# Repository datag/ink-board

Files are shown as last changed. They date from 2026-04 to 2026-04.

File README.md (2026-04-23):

# ink-board

A WiFi-connected tri-color ePaper display that shows a live dashboard — electricity price, solar power, weather, Bitcoin, and more — in a 3D-printed enclosure sitting on your desk.

<p align="center">
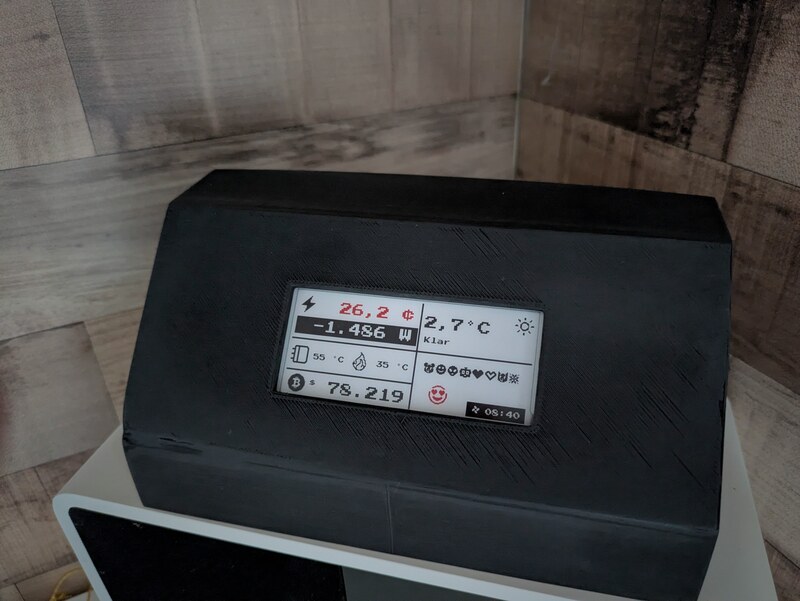
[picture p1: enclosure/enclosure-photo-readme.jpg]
ink-board on a desk, showing the live dashboard on its angled ePaper display
  
</p>

> [!NOTE]
> Most parts of this project — firmware, dashboard renderer, and enclosure design — were created with the help of AI. The whole thing is an experiment in building real hardware with AI assistance.

---

## How it works

```mermaid
graph TD
    A[Dashboard renderer<br/>Node.js] -->|POST /update — BMP over WiFi| B[ESP8266 firmware]
    B --> C[Waveshare 2.9&quot; B<br/>296 × 128 px · black / white / red]
    C --> D[3D-printed enclosure<br/>160 × 80 × 80 mm · 45° angled face]
    A -->|Fetches| E[(Live data<br/>Tibber · OpenMeteo · Binance · …)]
```

1. The **firmware** connects to WiFi and serves a small HTTP API. On boot it shows its IP address on the display.
2. The **dashboard renderer** runs on any machine on the same network, fetches live data from external APIs (Tibber, OpenMeteo, Binance, …), renders a 296 × 128 image, and pushes it to the device every few minutes.
3. The **enclosure** is a 3D-printed shell with a chamfered top edge so the display faces the viewer at a comfortable angle.

---

## Modules

| Module | Description | Docs |
|---|---|---|
| **Firmware** | ESP8266 Arduino sketch — WiFi, HTTP server, ePaper driver | [firmware.instructions.md](.github/instructions/firmware.instructions.md) |
| **Dashboard** | Node.js renderer — data fetching, SVG layout, BMP upload | [README.md](dashboard/README.md) · [dashboard.instructions.md](.github/instructions/dashboard.instructions.md) |
| **Enclosure** | OpenSCAD 3D-printable box with angled display window | [enclosure.instructions.md](.github/instructions/enclosure.instructions.md) |

---

## Hardware

| Part | Details |
|---|---|
| MCU | ESP8266 (NodeMCU 1.0 / ESP-12E) |
| Display | Waveshare 2.9" B V4 — 296 × 128 px, tri-color (black / white / red) |
| Interface | SPI (hardware) |
| Power | USB via NodeMCU onboard regulator |
| Enclosure | PLA, printed upside-down, no supports needed |

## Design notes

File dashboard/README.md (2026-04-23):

# ink-board Dashboard

## Setup

```shell
nvm use
npm install
```

> [!NOTE]
> Might require these dependencies to be installed globally:
> `sudo apt install libpixman-1-dev libcairo2-dev libpango1.0-dev libjpeg62-turbo-dev libgif-dev`

## Configure

Copy `dashboard.json5.example` to `dashboard.json5` and edit the configuration.

## Run

```shell
node render.js --config dashboard.json5

# Write SVG/PNG/BMP intermediate files but doesn't publish to device
node render.js --config dashboard.json5 --svg --png --bmp --dry-run
```

## Fetch data

```shell
# Run all enabled data-fetching scripts
node fetch.js --config dashboard.json5
```

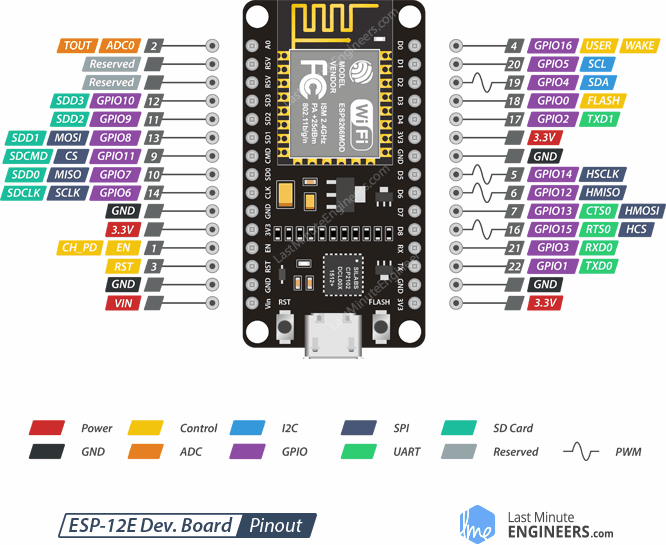
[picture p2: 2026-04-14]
firmware/doc/board-schematic.png

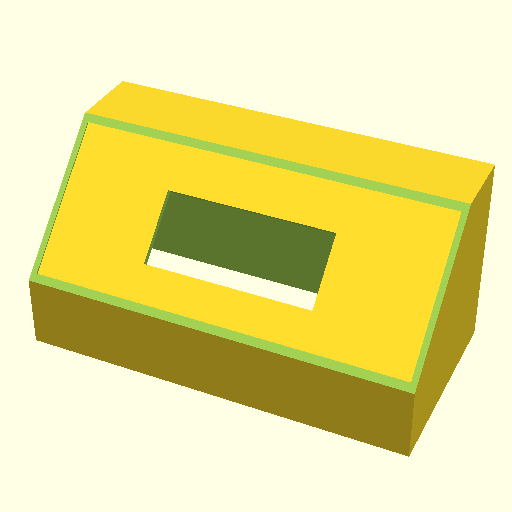
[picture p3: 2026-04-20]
enclosure/render_iso.png

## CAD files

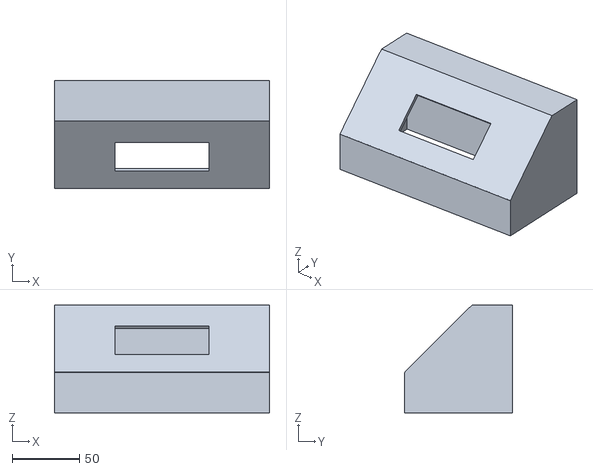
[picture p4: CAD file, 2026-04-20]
enclosure/ink-board.stl
160.0 x 80.0 x 80.0

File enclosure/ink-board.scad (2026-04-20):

// enclosure/ink-board.scad
// First-version: hollow box with 45° chamfer on long side
// No fillets, no display slot. Inner cavity clipped so angled face remains solid.

// Parameters
L = 160;      // outer length (mm)
W = 80;       // outer width  (mm)
H = 80;       // outer height (mm)
wall_t = 2.5; // wall thickness (mm)
chamfer = 50; // chamfer height from top (mm)

eps = 1; // small oversize to avoid boolean artifacts

module outer_box() {
  // bottom at Z=0 (open), extend to Z=H
  translate([0, 0, 0]) cube([L, W, H], center=false);
}

module inner_cavity() {
  // inner cavity extends up to leave wall_t at the top (fully hollow enclosure)
  inner_h = max(0, H - wall_t); // cavity height, leave top wall thickness
  inner_x = max(0, L - 2*wall_t);
  inner_y = max(0, W - 2*wall_t);
  translate([wall_t, wall_t, 0]) cube([inner_x, inner_y, inner_h], center=false);
}

module chamfer_wedge() {
  // Triangular prism removed from top-front-long edge
  // Built with linear_extrude of a right triangle as in model.txt
  points = [ [-H - eps, chamfer + eps], [-H - eps, 0], [-H + chamfer, 0] ];
  // rotate so extrusion axis aligns with world X
  rotate([0, 90, 0]) linear_extrude(height = L + 2*eps) polygon(points);
}

// Chamfer panel: solid panel that covers the chamfer face (thickness = wall_t)
module chamfer_panel() {
  // panel centered on chamfer face; small eps oversize to ensure clean booleans
  face_w = chamfer * sqrt(2); // true face width along the angled face
  translate([L/2, chamfer/2, H - chamfer/2 - wall_t + 1])
    rotate([45, 0, 0])
      cube([L, face_w - wall_t, wall_t], center=true);
}

// Display slot parameters
slot_l = 70; // mm (visible width along X)
slot_w = 30; // mm (visible height across face)
slot_cut = wall_t + 4; // cutter depth to ensure full cut-through

module display_slot() {
  // cutter box centered on the chamfer face, rotated so it cuts perpendicular to face
  // Reorder cube dimensions so the face-visible height uses slot_w (30 mm)
  translate([L/2, chamfer/2, H - chamfer/2 - wall_t])
    rotate([45, 0, 0])
      translate([-slot_l/2, -slot_w/2, -slot_cut/2])
        cube([slot_l, slot_w, slot_cut]);
}

// Final model: union of chamfered shell + panel, then subtract the slot so it is centered
difference() {
  union() {
    difference() {
      outer_box();
      inner_cavity();
      chamfer_wedge();
    }
    chamfer_panel();
  }
  display_slot();
}

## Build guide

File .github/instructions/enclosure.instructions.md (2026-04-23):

---
applyTo: "enclosure/**"
---

# Copilot instructions for ink-board enclosure

This module contains the OpenSCAD design for a 3D-printable enclosure for the
ink-board ePaper device. See `enclosure/model.txt` for the full model description.

## Render and inspect commands

OpenSCAD version 2021.01 is installed. Always use the CLI for renders — do NOT
open the GUI. The working directory for all commands is `enclosure/`.

```bash
# Isometric perspective render (beauty shot)
openscad --render \
  --camera=80,40,100,55,0,25,350 \
  --imgsize=1200x800 \
  -o render_iso.png ink-board.scad

# Face-on render (looking straight at the angled display face)
openscad --render \
  --camera=80,-60,65,90,0,0,200 \
  --imgsize=1200x800 \
  -o /tmp/face_on.png ink-board.scad

# Top-down render
openscad --render \
  --camera=80,40,200,0,0,0,200 \
  --imgsize=1200x800 \
  -o /tmp/top_down.png ink-board.scad

# Cross-section at X=80 (midpoint along length) — useful for slot debugging
# Use intersection() in a wrapper script or add a temporary slab in the .scad
```

Camera parameter format: `tx,ty,tz,rx,ry,rz,dist`
- `tx,ty,tz` — look-at target (translate)
- `rx,ry,rz` — camera rotation in degrees
- `dist`     — distance from target

`--render` forces full CGAL evaluation (catches mesh errors). Omit for faster
preview-quality renders during iteration.

## File structure

```
enclosure/
  ink-board.scad    — sole design file; all geometry defined here
  model.txt         — durable prose description of the intended model
  render_iso.png    — committed beauty render (regenerate after design changes)
```

## Model overview

A bottom-less box (160 × 80 × 80 mm, wall 2.5 mm) printed upside-down.
A 45° chamfer (leg = 30 mm) is cut from the top-front-long edge, creating an
angled face (≈42.4 mm wide, 160 mm long) with a 70 × 30 mm display window.
The outer box has 1.5 mm fillets on all visible edges.

Key parameters (all mm):

| Symbol | Value | Meaning |
|---|---|---|
| `L` | 160 | outer length |
| `W` |  80 | outer width |
| `H` |  80 | outer height |
| `wall_t` | 2.5 | wall thickness (all sides + top) |
| `chamfer`  |  30 | 45° chamfer leg — face width = chamfer × √2  |
| `slot_l` |  70 | display slot length (along L) |
| `slot_w` |  30 | display slot width (across face) |
| `slot_cut` |  15 | cutter depth through face |
| `fillet_r` | 1.5 | outer edge fillet radius |
| `$fn` |  64 | circle/sphere resolution |

## Key geometry conventions

### Cross-section (YZ plane, short-end view)

```
     ___________
    /            |   ← 45° angled face (chamfer leg = 30 mm each side)
   |             |
   |             |   total height = 80 mm
   |_____________|   ← open bottom (Z = 0)
```

### Coordinate system
- X axis: along the 160 mm length (0 → 160)
- Y axis: from front (Y=0) to rear (Y=80)
- Z axis: from open bottom (Z=0) to closed top (Z=80)
- Angled face center in world coords: `(L/2, chamfer/2, H−chamfer/2)` = `(80, 15, 65)`
- Angled face outward normal: `[0, −1/√2, +1/√2]` (forward-upward)

### Chamfer wedge (linear_extrude approach)
The triangular prism is built with `rotate([0,90,0]) linear_extrude(L+2·eps)` of a
right-triangle polygon. The 2D polygon uses local coordinates where:
  `local_x = −world_z`,  `local_y = world_y`

Triangle vertices (CCW, positive area required):
```
[(−H−eps,  chamfer+eps),   // world (y=chamfer+eps, z=H+eps)
 (−H−eps,  0           ),  // world (y=0,           z=H+eps)
 (−H+chamfer, 0        )]  // world (y=0,           z=H−chamfer)
```
The `eps=1` oversizing ensures clean boolean subtraction at shared faces.

### Display slot rotation
`rotate([45, 0, 0])` aligns the cube's Z axis with the face outward normal,
so the cutter penetrates perpendicularly through the angled face.
The slot is centered at the face center before rotating.

## OpenSCAD module structure

```
filleted_box(l, w, h, r)   Solid box with filleted vertical edges and rounded top
                            corners; bottom rim stays sharp. Built with hull() of
                            cylinders (vertical edges) and spheres (top corners).

outer_shell()               Hollow shell: filleted_box minus inner cavity.
                            Inner cavity starts at Z=0 (open bottom), leaves
                            wall_t on all five closed sides.

chamfer_wedge()             Triangular prism removed from top-front-long edge.
                            Built via rotate([0,90,0]) + linear_extrude of a
                            right-triangle polygon — NOT polyhedron (see pitfalls).
                            Coordinate mapping: local_x = −world_z, local_y = world_y;
                            extrusion axis → world X.

display_slot()              Rectangular cutter (slot_l × slot_w × slot_cut) centered
                            on the angled face. Placed at the face center
                            (L/2, chamfer/2, H−chamfer/2), then rotate([45,0,0])
                            aligns the cut perpendicular to the face.

Main:  difference() { outer_shell(); chamfer_wedge(); display_slot(); }
```

## Print orientation

Model origin: open bottom at Z=0. Place on build plate with Z=0 face down (box
printed "upside-down"). The 45° angled face overhangs at 45° — within the typical
no-support threshold. All other faces are vertical or horizontal; no supports needed.

## Known pitfalls

### 1. Avoid `polyhedron` for the chamfer wedge
OpenSCAD's `polyhedron` with incorrect face winding produces a "mesh not closed"
CGAL error. Use `linear_extrude` + `polygon` instead (already done in the current
implementation).

### 2. Slot spans the full face (design bug — unfixed as of initial commit)
**Symptom**: From the front, the entire 42.4 mm × 160 mm chamfer area appears as a
large dark opening; the 70 × 30 mm slot boundary is invisible.

**Root cause**: `outer_shell()` hollows the box with an inner cavity that extends
into the chamfer region. After `chamfer_wedge()` removes the top-front corner, only
a ~3.54 mm thin shell wall remains on the angled face. The hollow box interior is
immediately behind it, making the whole chamfer region look like a gaping hole.

**Fix approach**: The angled face must be a solid panel with only the `display_slot`
as the opening. Options:
  - Clip the inner cavity to stop at `Z = H − chamfer` in the front-face region
  - Add a `chamfer_fill()` module that re-adds solid material at the face, then
    subtract only the `display_slot` through it

### 3. Cross-section renders appear blank
If a cross-section slab is too thin (<5 mm), or the camera `tx` target is outside
the model bounds, the render produces a blank image. Target the camera at the model
center `(80, 40, 40)` and increase slab thickness to ≥10 mm.

## Commit convention

After any design change, regenerate `render_iso.png` and include it in the commit
alongside the `.scad` change.

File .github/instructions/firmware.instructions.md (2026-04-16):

---
applyTo: "firmware/**"
---

# Copilot instructions for ink-board

This file tells Copilot sessions how to build, test, flash, and reason about this repository.

## Build, test, and lint commands
- Build: Use PlatformIO for all builds. From the `firmware/` directory:
  - Full build: `~/.platformio/penv/bin/pio run -e nodemcuv2`
  - Quiet build: `~/.platformio/penv/bin/pio run -e nodemcuv2 --silent`
- Flash/upload to a NodeMCU v2:
  - `~/.platformio/penv/bin/pio run -t upload -e nodemcuv2 --upload-port /dev/ttyUSB0`
- Serial monitor: `~/.platformio/penv/bin/pio device monitor -p /dev/ttyUSB0`
- Tests: No unit tests exist yet. If added under `firmware/test/`, run a single test via:
  - `~/.platformio/penv/bin/pio test -e nodemcuv2 -f <test_name>`
- `pio` is not on PATH; always use `~/.platformio/penv/bin/pio`.

## High-level architecture
- **Target**: ESP8266 (NodeMCU 1.0 / ESP-12E), Arduino framework via PlatformIO (`env:nodemcuv2`).
- **Display**: Waveshare 2.9" ePaper (B) — 296×128 px, tri-color (black/white/red), SPI, driven by `GxEPD2_3C<GxEPD2_290_C90c, 8>` (page_height=8 saves ~9KB BSS) from the GxEPD2 library.
- **Entry point**: `firmware/src/main.cpp` — `setup()` connects to WiFi (credentials in `firmware/include/config.h`, gitignored), shows IP on the display, then starts an HTTP server. `loop()` calls `server.handleClient()`.
- **HTTP endpoints**:
  - `POST /update` — accepts a `multipart/form-data` BMP upload; renders it on the display.
  - `POST /clear` — clears the display to white.
- **Build flow**: PlatformIO compiles `firmware/src/` and links against GxEPD2 + Adafruit GFX Library; output at `firmware/.pio/build/nodemcuv2/firmware.bin`.

## Key conventions and repository-specific patterns

### SPI / display wiring (NodeMCU 1.0 ESP-12E → Waveshare 2.9" B)
| Signal | NodeMCU pin | GPIO |
|---|---|---|
| DIN (MOSI) | D7 | 13 |
| CLK (SCK)  | D5 | 14 |
| CS | D8 | 15 |
| DC | D2 |  4 |
| RST | D1 |  5 |
| BUSY | D6 | 12 |

Use `SS` (alias for GPIO15/D8) as `EPD_CS` in code to stay portable. GPIO0 (D3) and GPIO2 (D4) are boot-sensitive pins; avoid them for display control lines.

### GxEPD2 usage patterns
- Driver class for this display: `GxEPD2_3C<GxEPD2_290_C90c, 8>` (use page_height=8 to keep BSS small — saves ~9KB vs HEIGHT=296).
- Actual driver: `GxEPD2_290_C90c` (SSD1680 controller), used on Waveshare 2.9" B **V4** and V2.1 boards.
- Include the 3-color driver as `#include <epd3c/GxEPD2_290_C90c.h>`.
- Always wrap drawing calls in a `firstPage() … nextPage()` picture loop; never call `display()` directly on a paged display.
- Use `init(115200, true, 2, false)` for Waveshare V2.1+ boards (shorter reset pulse). Fall back to `init(115200)` if unsure.
- Drawing colors: `GxEPD_WHITE`, `GxEPD_BLACK`, `GxEPD_RED` (aliased to `GxEPD_COLORED`).
- For 3-color bitmaps, call `drawBitmap()` twice inside the page loop — once with `GxEPD_BLACK` and the black plane, once with `GxEPD_RED` and the red plane.
- Store bitmaps in `PROGMEM`; format is MSB-first, 1 bit per pixel, rows padded to byte boundaries.

### platformio.ini is authoritative
Add all build flags, library deps, upload settings, and monitor options to `firmware/platformio.ini`. Current deps:
```
lib_deps =
  zinggjm/GxEPD2
  adafruit/Adafruit GFX Library
```

### WiFi credentials
- Copy `firmware/include/config.h.example` to `firmware/include/config.h` and fill in real credentials.
- `firmware/include/config.h` is gitignored — never commit it.

### BMP upload workflow
The `/update` endpoint accepts `multipart/form-data` to avoid ESP8266WebServer buffering the entire body (which would OOM at 113KB). Use:
```bash
curl http://<IP>/update -F "file=@image.bmp;type=image/bmp"
```
Image requirements:
- 296×128 pixels, 24-bit uncompressed BMP (no compression, no color table)
- Top-down (negative height) or bottom-up — both are handled
- Color quantization: R>180 & G<80 & B<80 → red; luminance < 128 → black; else white

To generate a compatible BMP from any image:
```bash
firmware/tools/png2bmp.sh input.png output.bmp
```

### LED / GPIO
- The previous LED blink demo has been replaced by the ePaper sketch. `LED_BUILTIN` on NodeMCU ESP-12E is GPIO2 (D4, active-low); it is not used by the current firmware.
- Avoid GPIO0 (D3) and GPIO2 (D4) for control signals if possible — they affect boot mode if driven low at power-on.

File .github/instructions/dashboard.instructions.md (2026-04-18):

---
applyTo: "dashboard/**"
---

# Copilot instructions for ink-board dashboard

This module renders a tri-color ePaper dashboard image and uploads it to an ink-board device via HTTP.

## Build, run, and test commands
- Install dependencies: `npm install` (from `dashboard/`)
- Render and upload: `node render.js --config dashboard.json5`
- Dry-run (no upload): `node render.js --config dashboard.json5 --dry-run`
- Save intermediate outputs: use --svg, --png and --bmp to write dashboard.svg, dashboard.png and dashboard.bmp respectively. All options default to off. Forms supported: --svg (writes to data_dir/dashboard.svg), --svg=path or --svg <path> (writes to the given path). Same for --png and --bmp. Agents should always set all three when running; for visual inspections prefer the PNG output.
- Always pass `--config dashboard.json5` explicitly when running render.js.
- **Always add `--debug`** when running render.js as an agent — this bypasses `max_age` staleness checks so data files are read regardless of age (the flag has no other effect; `max_age` is still required in config).
- Fetch all enabled data sources: `node fetch.js`
- Run one data script directly: `node scripts/tibber.js`, `node scripts/binance.js`, `node scripts/weather.js`
- No automated tests exist yet.

## High-level architecture
- **Entry point**: `render.js` — parses CLI args, orchestrates the pipeline.
- **Pipeline**: config → data → layout → SVG → (optional: PNG (via canvg + node-canvas)) → BMP → HTTP upload. The bitmap is now rasterised from the generated SVG by default.
- **Runtime**: Node.js ≥18, ESM (`"type": "module"`).

### Source files (`src/`)
| File | Responsibility |
|---|---|
| `config.js` | Loads and validates `dashboard.json5` |
| `dataLoader.js` | Reads hot-folder files from `data_dir`, checks staleness, returns a `vars` dict |
| `layout.js` | Loads and validates the layout file (.js or .json5); compiles modifiers |
| `renderer.js` | Converts layout + data → SVG string (layoutToSvg). Registers fonts used by the SVG renderer. |
| `converter.js` | Converts SVG → PNG (canvg + node-canvas) and PNG → BMP via the JS bmp-writer (in src/bmp-writer.js) |
| `uploader.js` | POSTs BMP to the device at `POST /update` |

### Data-fetching scripts (`scripts/`)
Each script reads config (`--config` flag, defaults to `dashboard.json5`), fetches from an external API, and writes one or more JSON files to `device.data_dir`. Scripts are enabled via `scripts.{key}.enabled: true` in the config.

| Script | Writes | Key config keys |
|---|---|---|
| `tibber.js` | `tibber_price.json`, `tibber_power.json` | `scripts.tibber.access_token` |
| `binance.js` | `binance_{symbol}.json` | `scripts.binance.symbol`, `scripts.binance.api_key` |
| `weather.js` | `weather.json` | `scripts.weather.lat`, `scripts.weather.lon` |

`fetch.js` (project root) iterates `scripts.*` in config order, spawns each enabled script, streams its output, and prints ✓/✗ per script without aborting on failure.

### Configuration
- `dashboard.json5` (gitignored) is the live config; `dashboard.example.json5` is the committed template.
- Config specifies `device.url`, `device.data_dir`, `device.layout`, `sources[]`, and `scripts.*`.
- Always add new config keys to `dashboard.example.json5` — never commit `dashboard.json5`.

### Layout files
- Layout files live under `layouts/` and are referenced by `device.layout` in config.
- **Prefer `.js` (ES module, `export default { background, widgets }`)** — enables native functions.
- `.json5` is also supported for backward compatibility; modifiers must be serialized function strings.
- `loadLayout` is async; always `await` it.

### Output image constraints
- Must be exactly **296×128 pixels** to match the Waveshare 2.9" B display.
- Only three colors are valid: `#000000`, `#ffffff`, `#ff0000` — validated at load time, no others.

### Widget modifier pattern
Any widget can have an optional `modifier: (widget, vars) => Partial<Widget>` function. It is called at render time with the static widget config and the live data `vars` dict. The return value is shallowly merged onto the widget before rendering. Returning `{}` means no override.

Always guard against stale placeholders — when the raw value is not a number, return `{}`:
```js
modifier: (widget, vars) => {
  const n = Number(vars.my_source);
  return isNaN(n) ? {} : { text: /* formatted value */ };
}
```

### Number formatting convention
Use `de-DE` locale throughout — `.` as thousands separator, `,` as decimal separator:
```js
// Integer with thousands sep
new Intl.NumberFormat('de-DE', { maximumFractionDigits: 0 }).format(n)
// Fixed decimal
n.toLocaleString('de-DE', { minimumFractionDigits: 1, maximumFractionDigits: 1 })
// Time (Europe/Berlin)
new Intl.DateTimeFormat('de-DE', { timeZone: 'Europe/Berlin', hour: '2-digit', minute: '2-digit' }).format(new Date())
```

### Fonts
- Custom fonts live under `dashboard/fonts/`; `renderer.js` registers them with node-canvas at startup.
- **Press Start 2P** is the standard font: 8px ≈ Adafruit GFX size 1 (labels), 16px ≈ size 2 (values).
- `textBaseline = 'top'` — widget `y` is the **top** of the glyph box, not the baseline.

Rendering note:
- SVG → PNG rasterisation uses Canvg (in-process) and will use fonts registered by `renderer.js`. If Canvg or the DOM parser fails, the pipeline falls back to rasterising the SVG via a data-URL and `canvas.loadImage`; a warning is logged when this occurs. The PNG is saved to `device.data_dir/debug.png` on every run.
### Key conventions
- All source files use ES modules (`import`/`export`); no CommonJS.
- Prefer `async`/`await` over callbacks or raw Promise chains.
- Keep `render.js` as a thin orchestrator — business logic belongs in `src/`.
- Each `scripts/*.js` file follows the same pattern: `parseArgs` → `loadConfig` → fetch → `writeFileSync`.
- `dashboard.json5` is gitignored; always edit `dashboard.example.json5` to document new config keys.

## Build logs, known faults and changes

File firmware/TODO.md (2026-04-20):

# TODO

Firmware TODOs.

- [ ] Retry WiFi connection on failure
- [ ] Replace text/plain response on / with minimalistic web interface allowing to
  - [ ] Clear the display (for longer power-off)
  - [ ] Upload an image
- New endpoint /demo
- Option for /update that prevents (automated) updates for a period of time; so that a custom image could be shown and wouldn't be overwritten on the next external update

## Done

- [x] Verify that ePaper display is powered-off after a refresh

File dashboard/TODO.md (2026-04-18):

# TODO

Dashboard TODOs.

- [ ] Get rid of Node 18 requirement and upgrade to latest Node version.
  - [] Use pnpm

## Features

- [ ] Binance: 24hr price change (and price color, and up/down arrow)
- [ ] Another icon font with size 16px (iconfont with 24px is often too big for dashboard)
- [ ] Mode where the dashboard SVG is not built from definition, but itself is the template (which can then be enriched with modifiers)

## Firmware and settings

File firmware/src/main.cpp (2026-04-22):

// ink-board — WiFi + HTTP /update endpoint
//
// Wiring (hardware SPI, NodeMCU 1.0 / ESP-12E):
//   VCC -> 3V3  GND -> GND
//   DIN -> D7/GPIO13  CLK -> D5/GPIO14  CS -> D8/GPIO15
//   DC  -> D2/GPIO4   RST -> D1/GPIO5   BUSY -> D6/GPIO12

#include <Arduino.h>
#include <ESP8266WiFi.h>
#include <ESP8266WebServer.h>
#include <GxEPD2_3C.h>
#include <epd3c/GxEPD2_290_C90c.h>
#include "config.h"

// ── Display ──────────────────────────────────────────────────────────────────
#define EPD_CS   SS   // GPIO15 / D8
#define EPD_DC    4   // GPIO4  / D2
#define EPD_RST   5   // GPIO5  / D1
#define EPD_BUSY 12   // GPIO12 / D6

// page_height=8 keeps the display's internal buffers tiny (256 bytes vs 9472),
// freeing BSS memory for the heap.
GxEPD2_3C<GxEPD2_290_C90c, 8> display(
    GxEPD2_290_C90c(EPD_CS, EPD_DC, EPD_RST, EPD_BUSY));

static const uint16_t EPD_W       = 296;
static const uint16_t EPD_H       = 128;
static const uint16_t PLANE_BYTES = EPD_W / 8 * EPD_H;  // 4736

// ── Web server ────────────────────────────────────────────────────────────────
ESP8266WebServer server(80);

// ── Framebuffers (heap, allocated once at boot) ───────────────────────────────
static uint8_t* black_plane = nullptr;
static uint8_t* red_plane   = nullptr;

// ── Display helpers ───────────────────────────────────────────────────────────

static void renderPlanes() {
    display.setFullWindow();
    display.firstPage();
    do {
        display.fillScreen(GxEPD_WHITE);
        display.drawBitmap(0, 0, black_plane, EPD_W, EPD_H, GxEPD_BLACK);
        display.drawBitmap(0, 0, red_plane,   EPD_W, EPD_H, GxEPD_RED);
    } while (display.nextPage());
    display.hibernate();
}

static void showText(const char* line1, const char* line2 = nullptr,
                     const char* line3 = nullptr) {
    display.setFullWindow();
    display.firstPage();
    do {
        display.fillScreen(GxEPD_WHITE);
        display.setTextColor(GxEPD_BLACK);
        display.setTextSize(2);
        display.setCursor(8, 16);
        display.print(line1);
        if (line2) {
            display.setCursor(8, 52);
            display.print(line2);
        }
        if (line3) {
            display.setCursor(8, 88);
            display.print(line3);
        }
    } while (display.nextPage());
    display.hibernate();
}

static const char* wifiStatusName(uint8_t status) {
    switch (status) {
        case 0:   return "IDLE";
        case 1:   return "NO_SSID_AVAIL";
        case 2:   return "SCAN_DONE";
        case 4:   return "CONNECT_FAILED";
        case 5:   return "CONN_LOST";
        case 6:   return "DISCONNECTED";
        case 255: return "NO_SHIELD";
        default:  return "UNKNOWN";
    }
}

// ── BMP pixel helpers ─────────────────────────────────────────────────────────

static inline void paintPixel(int32_t x, int32_t y, uint8_t r, uint8_t g, uint8_t b) {
    if (x < 0 || x >= EPD_W || y < 0 || y >= EPD_H) return;
    uint32_t idx = (uint32_t)y * (EPD_W / 8) + (uint32_t)x / 8;
    uint8_t  bit = 0x80 >> (x % 8);
    if (r > 180 && g < 80 && b < 80) {
        red_plane[idx] |= bit;
    } else if (0.299f * r + 0.587f * g + 0.114f * b < 128.0f) {
        black_plane[idx] |= bit;
    }
}

// cls: 0 = white (no-op), 1 = black, 2 = red
static inline void paintPixelByClass(int32_t x, int32_t y, uint8_t cls) {
    if (x < 0 || x >= EPD_W || y < 0 || y >= EPD_H) return;
    uint32_t idx = (uint32_t)y * (EPD_W / 8) + (uint32_t)x / 8;
    uint8_t  bit = 0x80 >> (x % 8);
    if      (cls == 2) red_plane[idx]   |= bit;
    else if (cls == 1) black_plane[idx] |= bit;
}

// Classify an RGB color into 0=white, 1=black, 2=red
static inline uint8_t classifyColor(uint8_t r, uint8_t g, uint8_t b) {
    if (r > 180 && g < 80 && b < 80) return 2;
    if (0.299f * r + 0.587f * g + 0.114f * b < 128.0f) return 1;
    return 0;
}

// ── BMP upload state machine ──────────────────────────────────────────────────
// Processed chunk-by-chunk via the multipart upload handler, so the
// ESP8266WebServer never tries to buffer the full body in RAM.

static struct {
    uint8_t  hdr[54];           // file header (14 B) + DIB header (40 B)
    uint32_t hdrGot;
    uint32_t pixelOffset;       // byte offset to pixel data within the file
    uint32_t filePos;           // total bytes consumed so far
    int32_t  width, height;
    bool     topDown;
    uint16_t bpp;               // bits per pixel: 4, 8, or 24
    bool     indexed;           // true for 4-bit or 8-bit indexed modes
    uint8_t  colorClass[256];   // pre-classified palette: 0=white, 1=black, 2=red
    uint32_t colorTableGot;     // bytes of color table received so far
    uint32_t colorTableBytes;   // total color table size in bytes
    uint32_t rowStride;         // bytes per row, padded to 4-byte boundary
    int32_t  fileRow;           // next row index to decode
    uint32_t rowGot;            // bytes collected in rowBuf so far
    uint8_t  rowBuf[296];       // buffer for one row (max 296 px × 1 for 8-bit)
    bool     ok;
    const char* error;          // set when ok becomes false
} bmp;

static void feedBmpChunk(const uint8_t* data, size_t len) {
    if (!bmp.ok) return;

    while (len > 0) {
        if (bmp.hdrGot < 54) {
            // ── Collect 54-byte combined file+DIB header ──────────────────────
            size_t n = min(len, (size_t)(54 - bmp.hdrGot));
            memcpy(bmp.hdr + bmp.hdrGot, data, n);
            bmp.hdrGot += n; bmp.filePos += n; data += n; len -= n;

            if (bmp.hdrGot == 54) {
                if (bmp.hdr[0] != 'B' || bmp.hdr[1] != 'M') { bmp.ok = false; bmp.error = "not a BMP file"; return; }
                bmp.pixelOffset = (uint32_t)bmp.hdr[10] | ((uint32_t)bmp.hdr[11]<<8)
                                | ((uint32_t)bmp.hdr[12]<<16) | ((uint32_t)bmp.hdr[13]<<24);
                int32_t w = (int32_t)((uint32_t)bmp.hdr[18] | ((uint32_t)bmp.hdr[19]<<8)
                                    | ((uint32_t)bmp.hdr[20]<<16) | ((uint32_t)bmp.hdr[21]<<24));
                int32_t h = (int32_t)((uint32_t)bmp.hdr[22] | ((uint32_t)bmp.hdr[23]<<8)
                                    | ((uint32_t)bmp.hdr[24]<<16) | ((uint32_t)bmp.hdr[25]<<24));
                uint16_t bpp   = (uint16_t)bmp.hdr[28] | ((uint16_t)bmp.hdr[29]<<8);
                uint32_t compr = (uint32_t)bmp.hdr[30] | ((uint32_t)bmp.hdr[31]<<8)
                               | ((uint32_t)bmp.hdr[32]<<16) | ((uint32_t)bmp.hdr[33]<<24);
                if ((bpp != 4 && bpp != 8 && bpp != 24) || compr != 0) {
                    bmp.ok = false;
                    bmp.error = "need 4-bit, 8-bit, or 24-bit uncompressed BMP";
                    return;
                }
                bmp.topDown  = (h < 0);
                bmp.width    = w;
                bmp.height   = bmp.topDown ? -h : h;
                bmp.bpp      = bpp;
                bmp.indexed  = (bpp == 4 || bpp == 8);
                if      (bpp == 24) bmp.rowStride = ((uint32_t)w * 3 + 3) & ~3u;
                else if (bpp == 8)  bmp.rowStride = ((uint32_t)w     + 3) & ~3u;
                else                bmp.rowStride = (((uint32_t)w + 1) / 2 + 3) & ~3u;
                bmp.colorTableBytes = bmp.indexed ? (bmp.pixelOffset - 54) : 0;
                memset(black_plane, 0, PLANE_BYTES);
                memset(red_plane,   0, PLANE_BYTES);
            }
        } else if (bmp.indexed && bmp.colorTableGot < bmp.colorTableBytes) {
            // ── Read color table, pre-classify each 4-byte BGRA entry ─────────
            while (len > 0 && bmp.colorTableGot < bmp.colorTableBytes) {
                uint32_t entryIdx   = bmp.colorTableGot / 4;
                uint32_t byteInEntry = bmp.colorTableGot % 4;
                // rowBuf used as 4-byte scratch — safe, always within bounds
                bmp.rowBuf[byteInEntry] = *data++;
                bmp.colorTableGot++; bmp.filePos++; len--;
                if (byteInEntry == 3 && entryIdx < 256) {
                    // rowBuf layout: [0]=B [1]=G [2]=R [3]=reserved
                    bmp.colorClass[entryIdx] = classifyColor(bmp.rowBuf[2], bmp.rowBuf[1], bmp.rowBuf[0]);
                }
            }
        } else if (bmp.filePos < bmp.pixelOffset) {
            // ── Skip any extra bytes between color table and pixel data ────────
            size_t skip = min(len, (size_t)(bmp.pixelOffset - bmp.filePos));
            bmp.filePos += skip; data += skip; len -= skip;
        } else if (bmp.bpp == 24) {
            // ── 24-bit pixels: process one pixel (3 bytes) at a time ──────────
            // rowBuf[0..2] used as a 3-byte pixel accumulator; no full-row buffer
            // needed, so rowBuf[296] is sufficient even for 24-bit.
            uint32_t pixBytes = (uint32_t)bmp.width * 3;
            while (len > 0 && bmp.fileRow < bmp.height) {
                if (bmp.rowGot < pixBytes) {
                    uint32_t byteInPix = bmp.rowGot % 3;
                    bmp.rowBuf[byteInPix] = *data++;
                    bmp.rowGot++; bmp.filePos++; len--;
                    if (byteInPix == 2) {
                        int32_t y = bmp.topDown ? bmp.fileRow : (bmp.height - 1 - bmp.fileRow);
                        int32_t x = (int32_t)(bmp.rowGot / 3) - 1;
                        paintPixel(x, y, bmp.rowBuf[2], bmp.rowBuf[1], bmp.rowBuf[0]);
                    }
                } else {
                    // Skip row padding bytes (0–3 bytes to reach 4-byte boundary)
                    size_t skip = min(len, (size_t)(bmp.rowStride - bmp.rowGot));
                    bmp.rowGot += skip; bmp.filePos += skip; data += skip; len -= skip;
                }
                if (bmp.rowGot == bmp.rowStride) { bmp.fileRow++; bmp.rowGot = 0; }
            }
        } else {
            // ── Indexed pixels (4-bit / 8-bit): buffer full row then decode ────
            if (bmp.fileRow >= bmp.height) break;
            size_t n = min(len, (size_t)(bmp.rowStride - bmp.rowGot));
            memcpy(bmp.rowBuf + bmp.rowGot, data, n);
            bmp.rowGot += n; bmp.filePos += n; data += n; len -= n;

            if (bmp.rowGot == bmp.rowStride) {
                int32_t y = bmp.topDown ? bmp.fileRow : (bmp.height - 1 - bmp.fileRow);
                if (bmp.bpp == 8) {
                    for (int32_t x = 0; x < bmp.width; x++)
                        paintPixelByClass(x, y, bmp.colorClass[bmp.rowBuf[x]]);
                } else {  // 4-bit: two pixels per byte, high nibble first
                    for (int32_t x = 0; x < bmp.width; x++) {
                        uint8_t b  = bmp.rowBuf[x / 2];
                        uint8_t idx = (x & 1) ? (b & 0x0F) : (b >> 4);
                        paintPixelByClass(x, y, bmp.colorClass[idx]);
                    }
                }
                bmp.fileRow++;
                bmp.rowGot = 0;
            }
        }
    }
}

// ── HTTP handlers ─────────────────────────────────────────────────────────────

// Upload callback: receives the BMP in 1460-byte (max) chunks via multipart.
// ESP8266WebServer uses isForm=true for multipart, so it never buffers the body.
void handleUpload() {
    HTTPUpload& up = server.upload();
    if (up.status == UPLOAD_FILE_START) {
        memset(&bmp, 0, sizeof(bmp));
        bmp.ok    = true;
        bmp.error = nullptr;
    } else if (up.status == UPLOAD_FILE_WRITE) {
        feedBmpChunk(up.buf, up.currentSize);
    } else if (up.status == UPLOAD_FILE_END) {
        Serial.printf("[upload] %u bytes, %dx%d ok=%d freeHeap=%u\n",
                      up.totalSize, bmp.width, bmp.height, bmp.ok, ESP.getFreeHeap());
    }
}

// Called after the upload completes — send response then refresh display.
void handleUpdate() {
    if (!bmp.ok) {
        String msg = "BMP format error: ";
        msg += bmp.error ? bmp.error : "unknown";
        server.send(400, "text/plain", msg);
        return;
    }
    if (bmp.fileRow == 0) {
        server.send(400, "text/plain", "BMP decode error: no rows decoded (truncated upload?)");
        return;
    }
    server.send(200, "text/plain", "OK");
    server.client().flush();
    renderPlanes();
}

void handleClear() {
    memset(black_plane, 0, PLANE_BYTES);
    memset(red_plane,   0, PLANE_BYTES);
    server.send(200, "text/plain", "Clearing...");
    server.client().flush();
    display.setFullWindow();
    display.firstPage();
    do { display.fillScreen(GxEPD_WHITE); } while (display.nextPage());
    display.hibernate();
}

void handleRoot() {
    server.send(200, "text/plain",
        "ink-board\n"
        "POST /update  — multipart BMP upload (296x128, 4/8/24-bit uncompressed)\n"
        "POST /clear   — clear display\n"
        "\n"
        "Convert PNG to compatible BMP (requires ImageMagick):\n"
        "  # 4-bit indexed ~19KB (preferred):\n"
        "  tools/png2bmp.sh input.png output.bmp\n"
        "  # 8-bit indexed ~38KB:\n"
        "  tools/png2bmp.sh --8bit input.png output.bmp\n"
        "  # 24-bit ~113KB (legacy):\n"
        "  tools/png2bmp.sh --24bit input.png output.bmp\n"
        "\n"
        "Upload:\n"
        "  curl http://<ip>/update -F \"file=@output.bmp;type=image/bmp\"\n");
}

// ── WiFi helpers ──────────────────────────────────────────────────────────────

// Attempt one WiFi connection, polling for up to 20 seconds.
// Returns true if connected, false on timeout.
static bool connectWiFi() {
    showText("Connecting...", WIFI_SSID);
    Serial.printf("Connecting to %s\n", WIFI_SSID);
    WiFi.begin(WIFI_SSID, WIFI_PASS);
    uint32_t t = millis();
    while (WiFi.status() != WL_CONNECTED && millis() - t < 20000) {
        delay(500); Serial.print('.');
    }
    Serial.println();
    return WiFi.status() == WL_CONNECTED;
}

// ── Setup ─────────────────────────────────────────────────────────────────────

void setup() {
    Serial.begin(115200);
    delay(500);

    black_plane = new uint8_t[PLANE_BYTES]();
    red_plane   = new uint8_t[PLANE_BYTES]();

    display.init(115200, true, 2, false);
    display.setRotation(1);

    WiFi.persistent(false);
    WiFi.setAutoReconnect(true);
    WiFi.mode(WIFI_STA);

    while (!connectWiFi()) {
        uint8_t st = (uint8_t)WiFi.status();
        char errBuf[32];
        snprintf(errBuf, sizeof(errBuf), "Err %d: %s", st, wifiStatusName(st));
        showText("WiFi failed!", errBuf, "Retry in 60 s");
        Serial.println("WiFi connection failed! Retrying in 60 s...");
        WiFi.disconnect(true);
        delay(60000);
    }

    String ip = WiFi.localIP().toString();
    char infoBuf[24];
    snprintf(infoBuf, sizeof(infoBuf), "%d dBm  CH%d", WiFi.RSSI(), WiFi.channel());
    Serial.printf("Connected! IP: %s  RSSI: %d dBm  CH%d  freeHeap=%u\n",
                  ip.c_str(), WiFi.RSSI(), WiFi.channel(), ESP.getFreeHeap());
    showText("ink-board ready", ip.c_str(), infoBuf);

    server.collectHeaders("Content-Length", "Content-Type");
    server.on("/",       HTTP_GET,  handleRoot);
    server.on("/update", HTTP_POST, handleUpdate, handleUpload);
    server.on("/clear",  HTTP_POST, handleClear);
    server.begin();
    Serial.println("HTTP server started");
}

void loop() {
    server.handleClient();
}

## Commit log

2026-04-14 LED blick demo
2026-04-14 doc: Add board schematic for Amica NodeMCU 1.0 ESP-12E
2026-04-15 chore: move firmware files into firmware/
    Reorganise repo into two top-level directories:
    - firmware/ — all PlatformIO/Arduino firmware source
    - dashboard/ — dashboard renderer (to be added)
    Moves: src/ include/ lib/ test/ tools/ platformio.ini doc/ .vscode/
    Updates: .gitignore paths, .github/copilot-instructions.md
2026-04-15 feat(dashboard): add Node.js dashboard renderer
    Pipeline: hot-folder (*.json/*.txt) → staleness check → EJS template
    → Puppeteer screenshot (296×128) → png2bmp.sh 4-bit BMP → POST /update
    - render.js: CLI entry point (--config, --dry-run, --out)
    - src/config.js: JSON5 config parser + validator
    - src/dataLoader.js: hot-folder reader with per-source mtime staleness check
    - src/renderer.js: Puppeteer renderer (EJS → HTML → 296×128 PNG)
    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
2026-04-17 feat(Tibber): Show net power
2026-04-17 feat(firmware): show RSSI+channel on WiFi success, error code on failure
    On successful WiFi connection the boot screen now shows a third line
    with signal strength and channel (e.g. "-65 dBm CH6") below the IP.
    On connection failure the second line now contains the numeric status
    code together with a human-readable name (e.g. "Err 4: CONNECT_FAILED")
    instead of the generic "Check config.h" hint.
    Changes:
    - showText(): add optional line3 parameter rendered at y=88
    - wifiStatusName(): new helper mapping wl_status_t (0-6, 255) to names
    - setup(): pass RSSI+channel as line3 on success
    - setup(): pass error code+name as line2 on failure
    - Serial log on success now includes RSSI and channel
    Co-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
    [main.cpp]
2026-04-17 feat(dashboard): Strompreis/Leistung color-inversion thresholds
    - Fold cent sign into price string (no separate widget)
    - Price: black-inverted <=0ct, red-inverted >=28ct, red fg >=25ct
    - Power: black-inverted <=0W, red-inverted >3000W, red fg >1000W
2026-04-17 feat(dashboard): add --debug flag to bypass max_age staleness
    When --debug is passed, readSource() skips the age check so all
    present data files are read regardless of how old they are.
    max_age is still required in config; only the runtime gate is bypassed.
    Prints a visible notice: [debug] max_age ignored — ...
2026-04-18 feat: Add temperatures of hot water and stove
2026-04-20 Add first version of enclosure
    [ink-board.scad, ink-board.stl]
2026-04-22 firmware: retry WiFi on failure, enable auto-reconnect
    On initial connection failure, show an error on the display and retry
    after 60 seconds instead of halting. The connect-and-wait logic is
    extracted into a connectWiFi() helper called in a while loop.
    Add WiFi.setAutoReconnect(true) so the SDK transparently recovers
    dropped connections, and WiFi.persistent(false) to avoid unnecessary
    flash writes on each connect/disconnect cycle.
    [main.cpp]
2026-04-22 firmware: hibernate display after each paint
    The SSD1680 holds its image without power (bistable). Calling
    display.hibernate() after every paint puts the controller into deep
    sleep, eliminating quiescent draw between updates.
    No explicit re-init is needed before the next paint: GxEPD2 tracks
    _hibernating internally and auto-resets inside writeImage() →
    _Init_Part() → _InitDisplay().
    [main.cpp]
2026-05-03 bugfix(Tibber): Increase timeout for power
2026-05-03 feat(tibber): gate live power fetch behind fetchLivePower config flag
2026-05-03 feat(layout): fall back to power_monitoring for net power widget
    If tibber_power is stale (stale_placeholder —), resolveNetPower()
    computes net power as power_monitoring_power − power_monitoring_power_production.
2026-05-23 fix(dashboard): treat missing production as 0 in resolveNetPower
    If power_monitoring_power_production is absent or non-numeric, fall back
    to 0 instead of returning NaN, so net power still resolves correctly
    from consumption alone.
2026-06-13 New power consumption source
2026-10-11 feat(dashboard): use tcp probe for work host
    Avoid ping binary and unprivileged ICMP socket issues in containers.
    Treat connect and ECONNREFUSED (RST) as online with 2s timeout.
